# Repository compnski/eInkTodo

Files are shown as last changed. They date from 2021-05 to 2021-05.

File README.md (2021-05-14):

# E-Ink Todo List

A mess of Arduino C++, a local python proxy and some google apps script.

## Google Apps Script
This is used to get the calendar events and format into a easily parsable list. Copy the code from googleAppScript.gs into a project.
Then update the calendarId with your own, deploy it as a webapp and you're in business!
https://script.google.com/

## todoProxy.py
I was having an awful lot of trouble connecting to google via SSL. In particular, the apps script webapp sends a few Location header redirects and my ESP32 would get stuck after following one or two. No idea why.

My fix was to set up a local proxy on my computer. This also removes the need for an SSL client, removing one more troublesome part from the equation.

Update the taskURL with the URL of your google app script webapp, and you're good to go.

The /done/ stuff is hardcoded and not ready yet, eventually it'll take the event Id to mark it complete.

## Arduino code
This stuff is a huge pile of spaghetti C++. It's been maybe 10 years since I last wrote anything with C++ and it shows.
I've also not done too much Arduino, so have no idea how to setup the file structure.

For this, symlink todo.cpp into your Arduino folder as anything with a .ino file extension. Then add your SSID/password + taskURL. (Or create a secrets.h and copy/symlink that over too).

Then symlink the two library folders, HttpClient and TodoList into ~/Arduino/libraries, they should be found automatically.

You'll also need the ESP32 SDK and the waveshare SDK -- I used instructions from the waveshare wiki -- https://www.waveshare.com/wiki/7.5inch_HD_e-Paper_HAT_(B).

## Troubleshooting
The wifi only seems to connect like 1 in 100 times. It worked great in the prototype step, now, not so much. Good luck!

## TODO

1. Fetch temp / weather ?
1. Look into adding lines across for style
1. Checkmark for completed tasks
1. Red color for overdue tasks
1. Read buttons for done
1. Flash LED on overdue
1. Fix spacing and all that
1. Speaker / sound
1. Neopixels on top
1. Korean word of the day?? (First todo?)

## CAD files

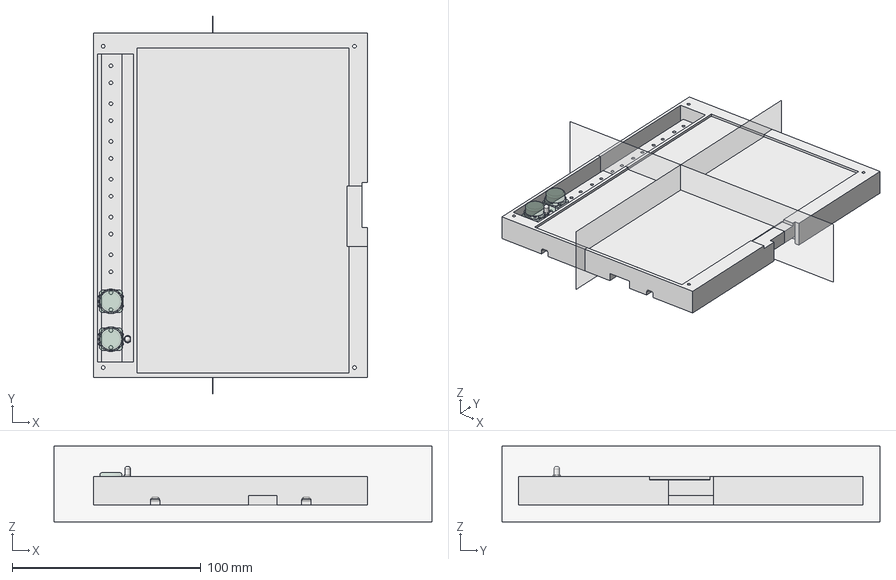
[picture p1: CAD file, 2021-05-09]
cad/eInkCase.FCStd
200.0 x 200.0 x 40.0 mm
V_Slice
H_Slice
BottomCase
12mmx12mm With Black cap round
LED 3mm Red 6mm Leads
12mmx12mm With Black cap round001

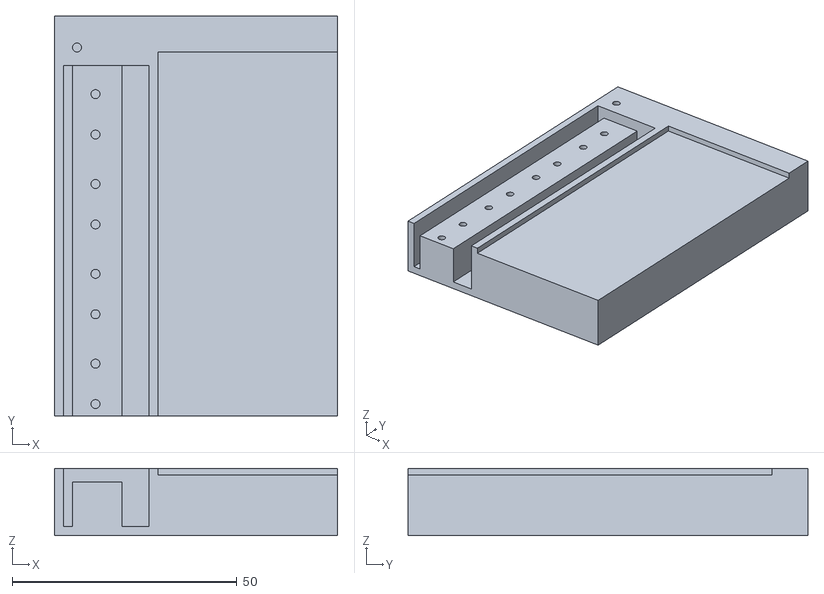
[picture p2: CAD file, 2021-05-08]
cad/stl/BottomCase-Slice3.stl
63.0 x 89.0 x 15.0

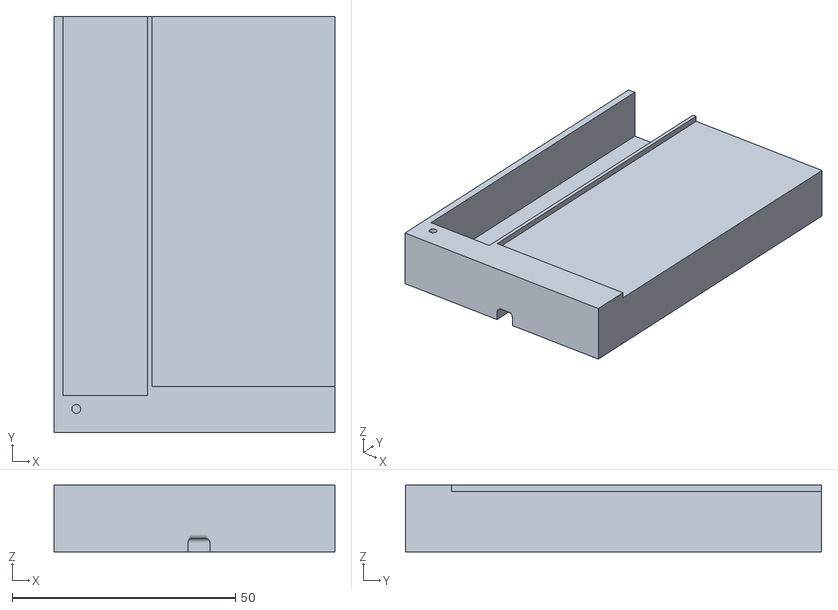
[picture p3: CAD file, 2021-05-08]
cad/stl/BottomCase-Slice1.stl
63.0 x 93.3 x 15.0

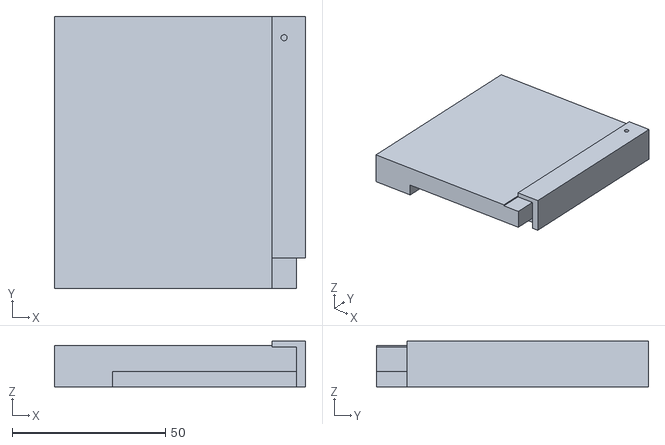
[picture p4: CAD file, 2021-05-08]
cad/stl/BottomCase-Slice2.stl
82.0 x 89.0 x 15.0

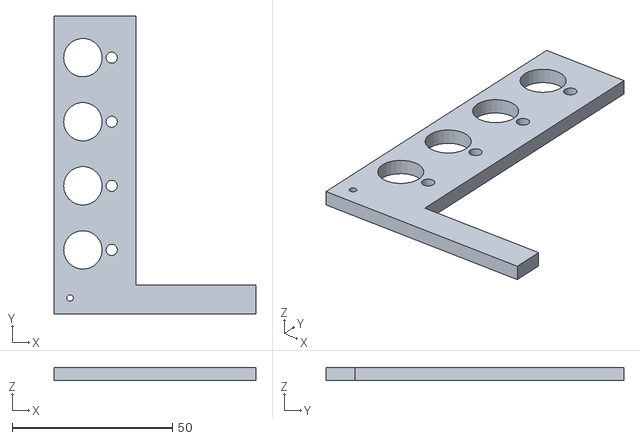
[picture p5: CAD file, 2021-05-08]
cad/stl/TopCase-Slice0.stl
63.0 x 93.0 x 4.00

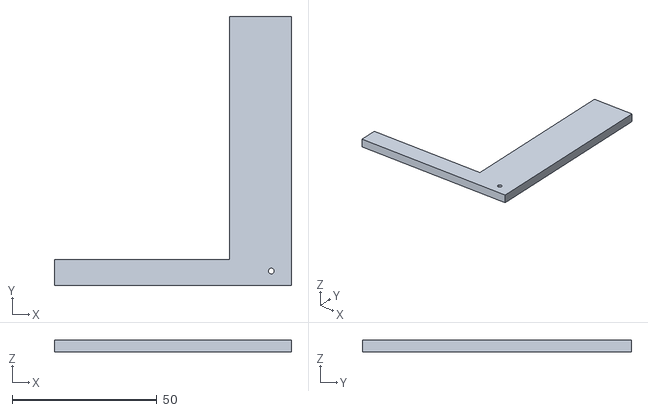
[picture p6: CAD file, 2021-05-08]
cad/stl/TopCase-Slice2.stl
82.0 x 93.0 x 4.00

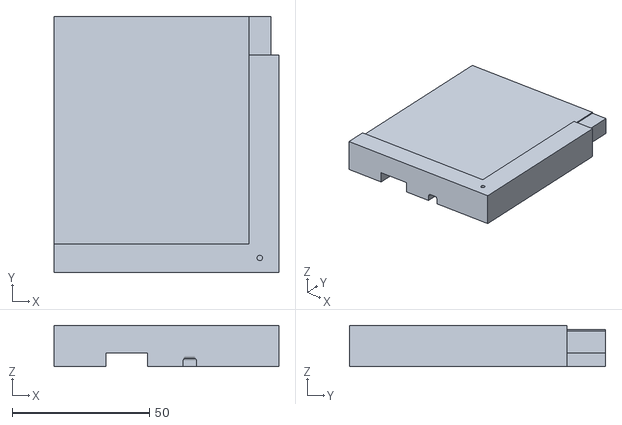
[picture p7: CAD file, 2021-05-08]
cad/stl/BottomCase-Slice0.stl
82.0 x 93.3 x 15.0

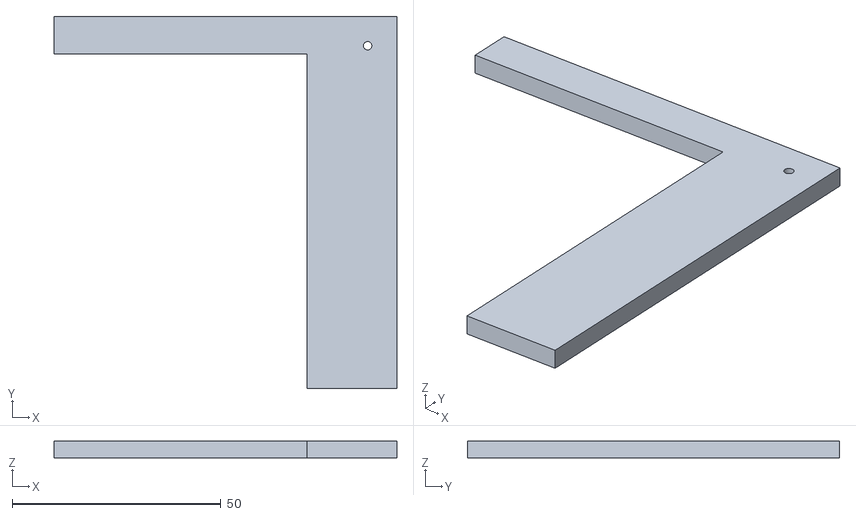
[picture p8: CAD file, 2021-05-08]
cad/stl/TopCase-Slice4.stl
82.0 x 89.0 x 4.00

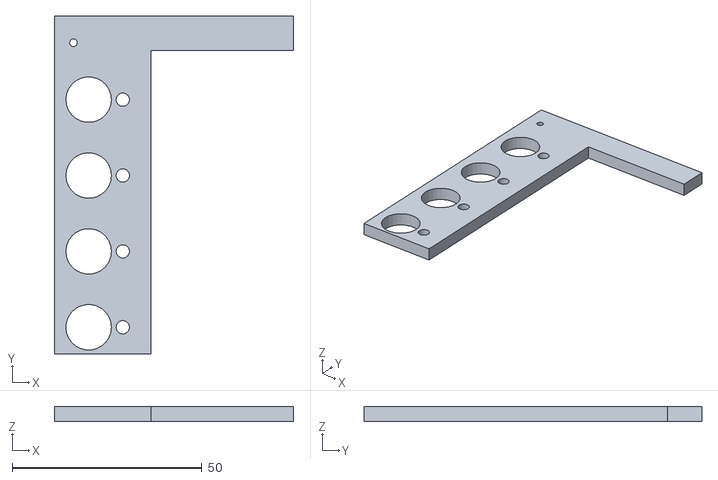
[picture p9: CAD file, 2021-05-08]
cad/stl/TopCase-Slice1.stl
63.0 x 89.0 x 4.00

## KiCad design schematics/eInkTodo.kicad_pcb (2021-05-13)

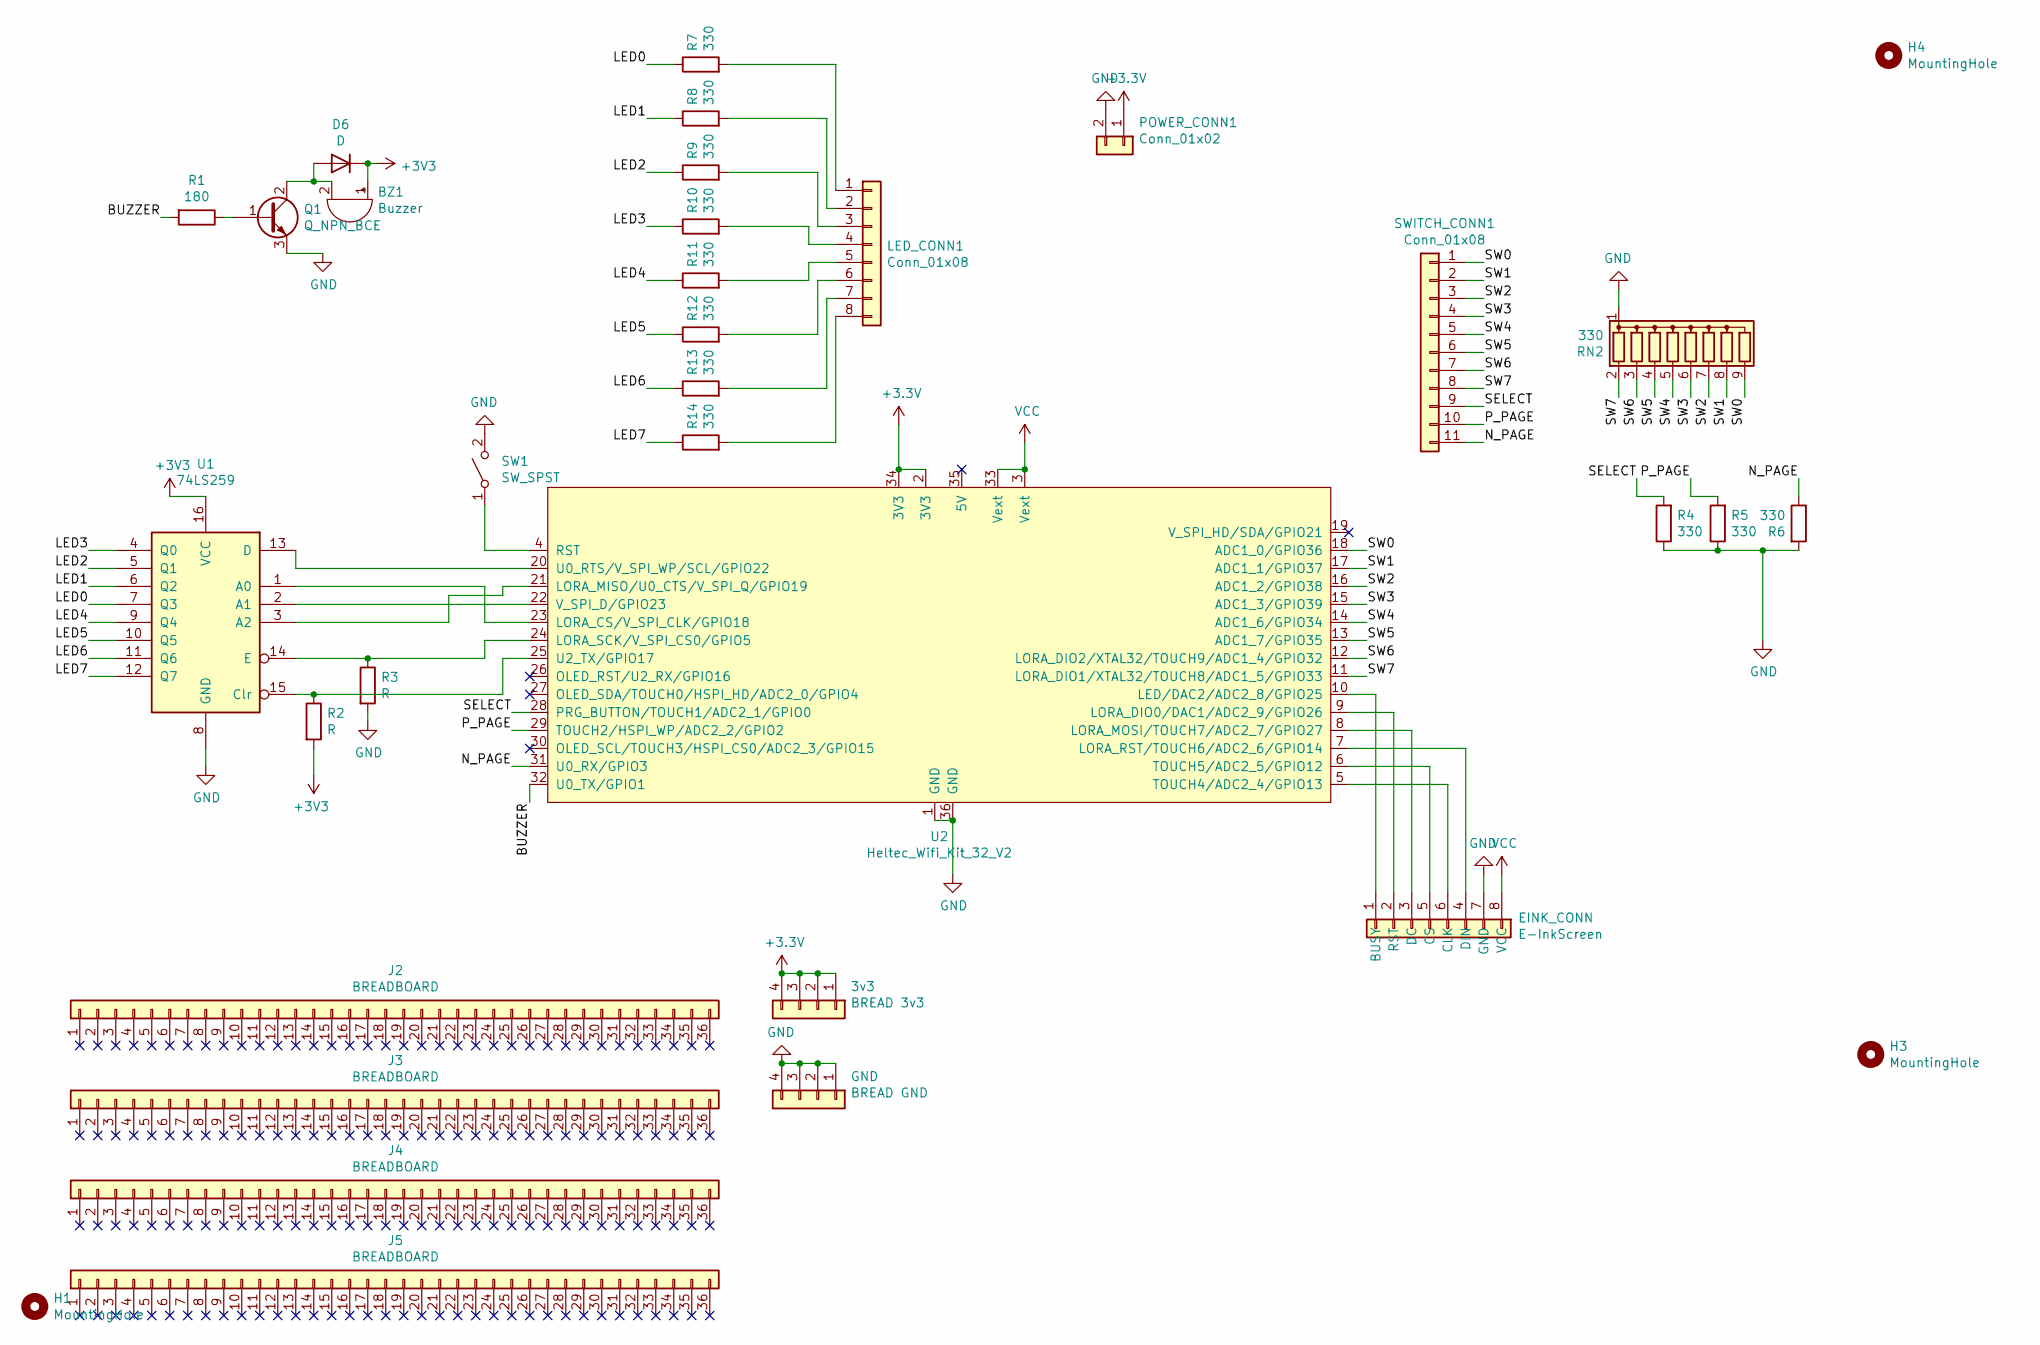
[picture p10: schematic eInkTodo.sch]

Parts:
3v3: BREAD 3v3; PinHeader_1x04_P2.54mm_Vertical
BZ1: Buzzer; MagneticBuzzer_CUI_CST-931RP-A
D6: D; D_DO-41_SOD81_P10.16mm_Horizontal
EINK_CONN: E-InkScreen; PinHeader_1x08_P2.54mm_Horizontal
GND: BREAD GND; PinHeader_1x04_P2.54mm_Vertical
H1, H3, H4: MountingHole; MountingHole_2.7mm_M2.5
J2, J3, J4, J5: BREADBOARD; PinHeader_1x36_P2.54mm_Vertical
LED_CONN1: Conn_01x08; PinHeader_1x08_P2.54mm_Horizontal
POWER_CONN1: Conn_01x02; PinHeader_1x02_P2.54mm_Horizontal
Q1: Q_NPN_BCE; TO-92_HandSolder
R1: 180; R_Axial_DIN0207_L6.3mm_D2.5mm_P10.16mm_Horizontal
R2, R3: R; R_Axial_DIN0207_L6.3mm_D2.5mm_P10.16mm_Horizontal
R4, R5, R6, R7, R8, R9, R10, R11, R12, R13, R14: 330; R_Axial_DIN0207_L6.3mm_D2.5mm_P10.16mm_Horizontal
RN2: 330; R_Array_SIP9
SW1: SW_SPST; PinHeader_1x02_P2.54mm_Vertical
SWITCH_CONN1: Conn_01x08; PinHeader_1x11_P2.54mm_Horizontal
U1: 74LS259; DIP-16_W7.62mm_LongPads
U2: Heltec_Wifi_Kit_32_V2; Heltec_WiFi_Kit_32

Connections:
/BUZZER: R1.2, U2.32 (U0_TX/GPIO1)
/LED0: R7.1, U1.7 (Q3)
/LED1: R8.1, U1.6 (Q2)
/LED2: R9.1, U1.5 (Q1)
/LED3: R10.1, U1.4 (Q0)
/LED4: R11.1, U1.9 (Q4)
/LED5: R12.1, U1.10 (Q5)
/LED6: R13.1, U1.11 (Q6)
/LED7: R14.1, U1.12 (Q7)
/N_PAGE: R6.1, SWITCH_CONN1.11, U2.31 (U0_RX/GPIO3)
/P_PAGE: R5.2, SWITCH_CONN1.10, U2.29 (TOUCH2/HSPI_WP/ADC2_2/GPIO2)
/SELECT: R4.2, SWITCH_CONN1.9, U2.28 (PRG_BUTTON/TOUCH1/ADC2_1/GPIO0)
/SW0: RN2.9 (R8), SWITCH_CONN1.1, U2.18 (ADC1_0/GPIO36)
/SW1: RN2.8 (R7), SWITCH_CONN1.2, U2.17 (ADC1_1/GPIO37)
/SW2: RN2.7 (R6), SWITCH_CONN1.3, U2.16 (ADC1_2/GPIO38)
/SW3: RN2.6 (R5), SWITCH_CONN1.4, U2.15 (ADC1_3/GPIO39)
/SW4: RN2.5 (R4), SWITCH_CONN1.5, U2.14 (ADC1_6/GPIO34)
/SW5: RN2.4 (R3), SWITCH_CONN1.6, U2.13 (ADC1_7/GPIO35)
/SW6: RN2.3 (R2), SWITCH_CONN1.7, U2.12 (LORA_DIO2/XTAL32/TOUCH9/ADC1_4/GPIO32)
/SW7: RN2.2 (R1), SWITCH_CONN1.8, U2.11 (LORA_DIO1/XTAL32/TOUCH8/ADC1_5/GPIO33)
GND: EINK_CONN.7 (GND), GND.1, GND.2, GND.3, GND.4, POWER_CONN1.2, Q1.3 (E), R3.2, R4.1, R5.1, R6.2, RN2.1 (common), SW1.2 (B), U1.8 (GND), U2.1 (GND), U2.36 (GND); also elsewhere on the board
unnamed: BZ1.2 (+), D6.2 (A), Q1.2 (C)
unnamed 22: EINK_CONN.1 (BUSY), U2.10 (LED/DAC2/ADC2_8/GPIO25); also elsewhere on the board
unnamed 23: EINK_CONN.2 (RST), U2.9 (LORA_DIO0/DAC1/ADC2_9/GPIO26); also elsewhere on the board
unnamed 24: EINK_CONN.3 (DC), U2.8 (LORA_MOSI/TOUCH7/ADC2_7/GPIO27); also elsewhere on the board
unnamed 25: EINK_CONN.4 (DIN), U2.7 (LORA_RST/TOUCH6/ADC2_6/GPIO14); also elsewhere on the board
unnamed 26: EINK_CONN.5 (CS), U2.6 (TOUCH5/ADC2_5/GPIO12); also elsewhere on the board
unnamed 27: EINK_CONN.6 (CLK), U2.5 (TOUCH4/ADC2_4/GPIO13); also elsewhere on the board
unnamed: LED_CONN1.1, R7.2
unnamed: LED_CONN1.2, R8.2
unnamed: LED_CONN1.3, R9.2
unnamed: LED_CONN1.4, R10.2
unnamed: LED_CONN1.5, R11.2
unnamed: LED_CONN1.6, R12.2
unnamed: LED_CONN1.7, R13.2
unnamed: LED_CONN1.8, R14.2
unnamed: Q1.1 (B), R1.1
unnamed: R2.1, U1.15 (Clr), U2.25 (U2_TX/GPIO17)
unnamed: R3.1, U1.14 (E), U2.24 (LORA_SCK/V_SPI_CS0/GPIO5)
unnamed: SW1.1 (A), U2.4 (RST)
unnamed: U1.1 (A0), U2.23 (LORA_CS/V_SPI_CLK/GPIO18)
unnamed: U1.2 (A1), U2.22 (V_SPI_D/GPIO23)
unnamed: U1.3 (A2), U2.21 (LORA_MISO/U0_CTS/V_SPI_Q/GPIO19)
unnamed: U1.13 (D), U2.20 (U0_RTS/V_SPI_WP/SCL/GPIO22)
VCC: EINK_CONN.8 (VCC), U2.3 (Vext), U2.33 (Vext); also elsewhere on the board

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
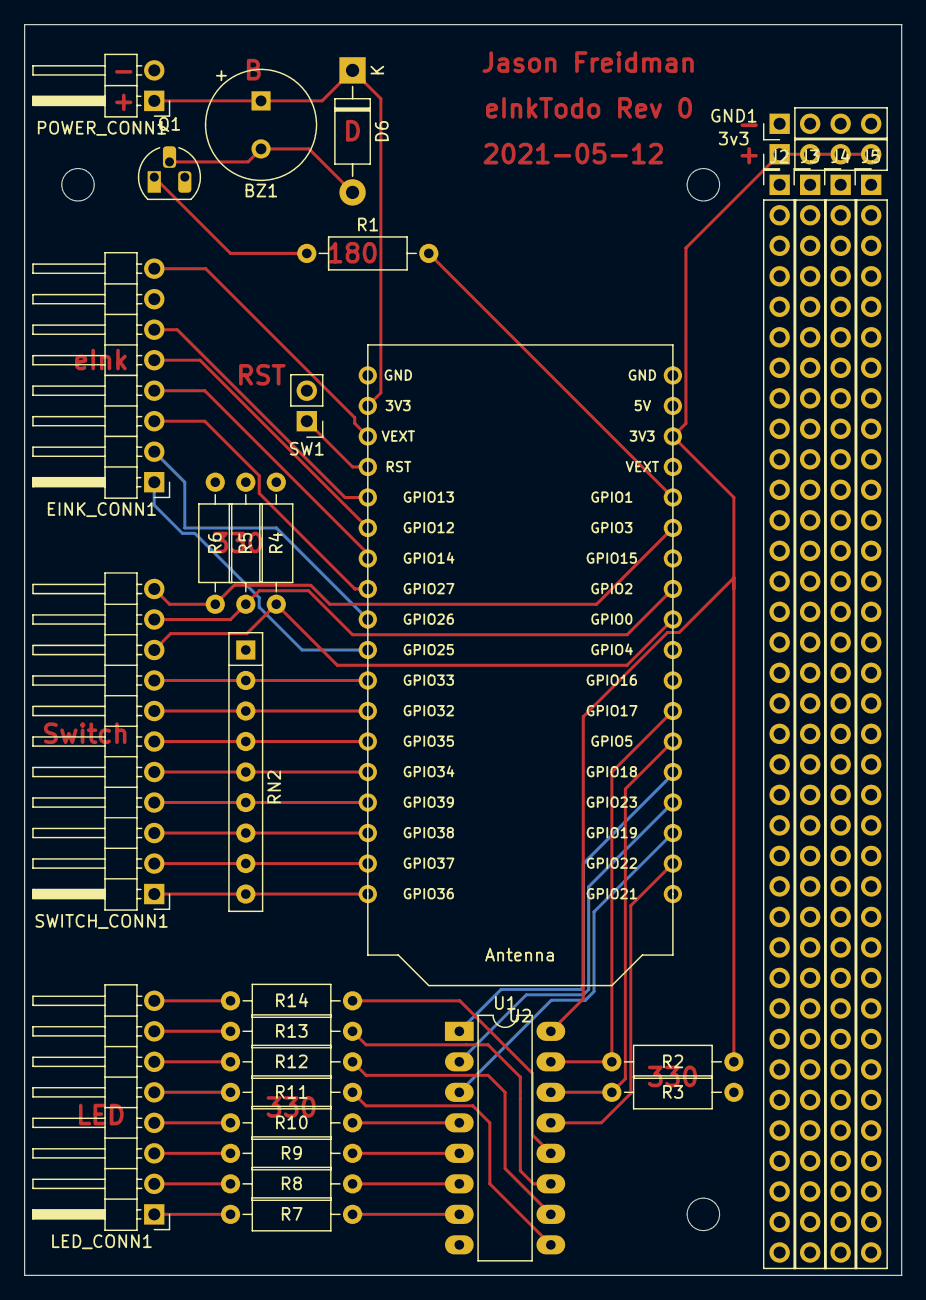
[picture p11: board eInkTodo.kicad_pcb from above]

Board: 2 copper layers, 73.0 x 104.1 mm, 34 parts (0 on the bottom side), 46 nets.

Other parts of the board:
EINK_CONN1: E-InkScreen; PinHeader_1x08_P2.54mm_Horizontal
GND1: BREAD GND; PinHeader_1x04_P2.54mm_Vertical

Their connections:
GND: EINK_CONN1.7, GND1.1, GND1.2, GND1.3, GND1.4; also elsewhere on the board
unnamed 22: EINK_CONN1.1; also elsewhere on the board
unnamed 23: EINK_CONN1.2; also elsewhere on the board
unnamed 24: EINK_CONN1.3; also elsewhere on the board
unnamed 25: EINK_CONN1.4; also elsewhere on the board
unnamed 26: EINK_CONN1.5; also elsewhere on the board
unnamed 27: EINK_CONN1.6; also elsewhere on the board
VCC: EINK_CONN1.8; also elsewhere on the board

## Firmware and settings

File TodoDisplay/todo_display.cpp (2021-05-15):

#include "todo_display.h"

#include "DEV_Config.h"
#include "EPD.h"
#include "GUI_Paint.h"
#include "eink.h"

// TODO: Pass in IP info
#include <WiFi.h>

const int TASK_TOP_OFFSET = 50;
const int TASK_LINE_HEIGHT = 107;

Latch::Latch(const uint8_t (&addressPins)[3], const uint8_t dataPin,
             const uint8_t enablePin, const uint8_t resetPin)
    : addressPins(addressPins), dataPin(dataPin), enablePin(enablePin),
      resetPin(resetPin) {
  reset();
}

void Latch::reset() {
  disable();
  digitalWrite(resetPin, 0);
  delay(1);
  digitalWrite(resetPin, 1);
  enable();
}

void Latch::disable() { digitalWrite(enablePin, 1); }
void Latch::enable() { digitalWrite(enablePin, 0); }

void Latch::set(uint8_t idx, uint8_t state) {
  disable();
  digitalWrite(addressPins[0], state & 0b001);
  digitalWrite(addressPins[1], state & 0b010);
  digitalWrite(addressPins[2], state & 0b100);
  enable();
}

// void TodoDisplay::clearLeds() {}

TodoDisplay::TodoDisplay(TodoList &list, Latch &ledLatch)
    : TodoDisplay(&list, &ledLatch) {}
TodoDisplay::TodoDisplay(TodoList *list, Latch *ledLatch)
    : todoList(list), ledLatch(ledLatch) {}

void TodoDisplay::drawTasks() {
  printf("Draw  tasks for %d \n", todoList->lastTimestamp);
  ledLatch->reset();
  for (int i = 0; i < todoList->numClientTasks; i += 1) {
    Paint_SelectImage(BlackImage);

    int y = i * TASK_LINE_HEIGHT + TASK_TOP_OFFSET;
    Task *task = todoList->taskList[i];
    printf("Task %s startAt %d dueAt %d ", task->title.c_str(), task->startAtTs,
           task->dueAtTs);
    if (task->isOverdue(todoList->lastTimestamp)) {
      ledLatch->set(i, 1);
      // digitalWrite(Led0, 1);
      Paint_SelectImage(RYImage);
    }

    printf("Draw at (%d, 10)\n", y);
    // Paint_DrawString_EN(0, y, "<", &Font24, BLACK, WHITE);
    Paint_DrawRectangle(30, y, 50, y + 20, BLACK, DOT_PIXEL_1X1,
                        DRAW_FILL_EMPTY);
    Paint_DrawString_EN(60, y, task->title.c_str(), &Font24, BLACK, WHITE);

    if (task->isDone == 1) {
      Paint_DrawLine(55, y + 12, Paint.Width - 5, y + 12, BLACK, DOT_PIXEL_1X1,
                     LINE_STYLE_SOLID);
      Paint_DrawString_EN(31, y, "x", &Font20, BLACK, WHITE);
    }
  }
}

void TodoDisplay::drawFrame() {
  printf("Draw frame\n");
  Paint_SelectImage(RYImage);
  Paint_Clear(WHITE);
  Paint_SelectImage(BlackImage);
  Paint_Clear(WHITE);

  // Paint_DrawLine(0, 30, Paint.Width, 30, BLACK, DOT_PIXEL_1X1,
  //                  LINE_STYLE_SOLID);
  Paint_DrawLine(0, 850, Paint.Width, 850, BLACK, DOT_PIXEL_1X1,
                 LINE_STYLE_SOLID);
  Paint_DrawString_EN(200, 865, WiFi.localIP().toString().c_str(), &Font12,
                      BLACK, WHITE);
}

void TodoDisplay::render() {
  drawFrame();
  drawTasks();

  printf("EPD_Display\r\n");
  EPD_7IN5B_HD_Display(BlackImage, RYImage);
}

void TodoDisplay::cleanup() {
  printf("Goto Sleep...\r\n");
  EPD_7IN5B_HD_Sleep();
  free(BlackImage);
  free(RYImage);
  BlackImage = NULL;
  RYImage = NULL;
}

void TodoDisplay::setup() {
  DEV_Module_Init();
  printf("EPD_7IN5B_HD_test Demo\r\n");
  printf("e-Paper Init and Clear...\r\n");
  EPD_7IN5B_HD_Init();
  EPD_7IN5B_HD_Clear();
  delay(500);
  printf("Set rotate\n");

  /* you have to edit the startup_stm32fxxx.s file and set a big enough heap
   * size */
  UWORD Imagesize =
      ((EPD_7IN5B_HD_WIDTH % 8 == 0) ? (EPD_7IN5B_HD_WIDTH / 8)
                                     : (EPD_7IN5B_HD_WIDTH / 8 + 1)) *
      EPD_7IN5B_HD_HEIGHT;
  if ((BlackImage = (UBYTE *)malloc(Imagesize)) == NULL) {
    printf("Failed to apply for black memory...\r\n");
    while (1)
      ;
  }
  if ((RYImage = (UBYTE *)malloc(Imagesize)) == NULL) {
    printf("Failed to apply for red memory...\r\n");
    while (1)
      ;
  }
  printf("NewImage:BlackImage and RYImage\r\n");
  Paint_NewImage(BlackImage, EPD_7IN5B_HD_WIDTH, EPD_7IN5B_HD_HEIGHT, ROTATE_90,
                 WHITE);
  Paint_NewImage(RYImage, EPD_7IN5B_HD_WIDTH, EPD_7IN5B_HD_HEIGHT, ROTATE_90,
                 WHITE);

  Paint_SelectImage(RYImage);
  Paint_Clear(WHITE);
  Paint_SelectImage(BlackImage);
  Paint_Clear(WHITE);
}

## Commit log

2021-05-08 Start schematic design for main board
    [eInkTodo.kicad_pcb, eInkTodo.sch]
2021-05-08 Initial CAD for case
    [BottomCase-Slice0.stl, BottomCase-Slice1.stl, BottomCase-Slice2.stl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]
2021-05-08 Add button rest
    [BottomCase-Slice3.stl, eInkCase.FCStd]
2021-05-08 Add missing schematic libraries. Were git-ignored.
2021-05-09 Update eink screen to match actual size
    [eInkCase.FCStd]
2021-05-09 Almost complete schematic. Use Net labels for clarity. Add a buzzer
    [eInkTodo.sch]
2021-05-13 Cleanup + factor e-ink display into a separate class.
    Also clean up how button and LEDs work
2021-05-13 Finish board layout
    [eInkTodo.kicad_pcb, eInkTodo.sch]
2021-05-14 ignore generated gerber files
2021-05-14 Fix code to actually compile and run
    [todo_display.cpp]
2021-05-14 Adjust height to fit frame
2021-05-15 Add latch for LEDs
2021-05-15 Update pin #s
    [eInkTodo.sch]
